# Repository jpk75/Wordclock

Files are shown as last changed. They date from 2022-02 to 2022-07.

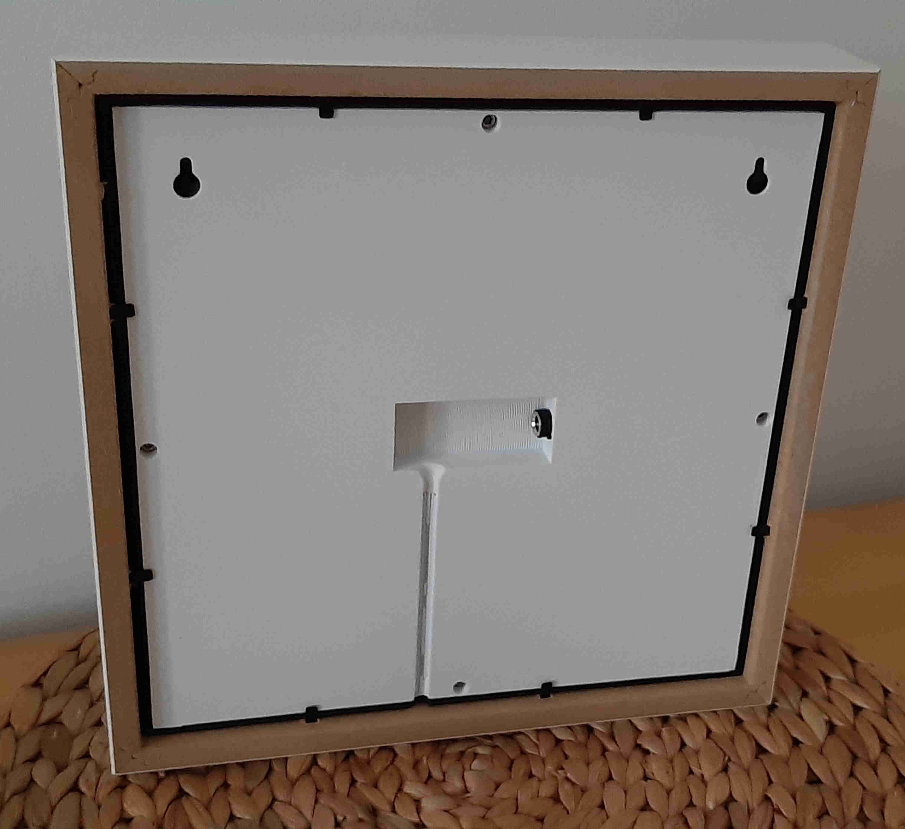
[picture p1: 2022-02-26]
doc/worclock_2.jpg

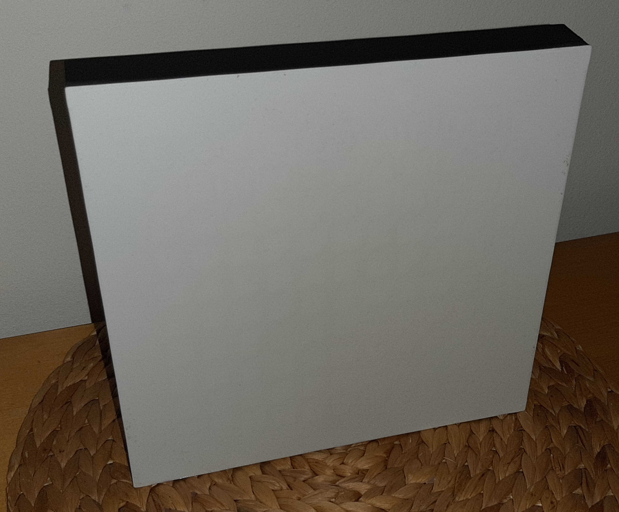
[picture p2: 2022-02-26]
doc/worclock_3.jpg

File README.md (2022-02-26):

# Wordclock

## Model
This project contains a parametric model, wiring description and software to create a wordclock.
Initially it was designed to fit for an IKEA Ribba frame of size 23x23, because I already have some of them at home. But it is possible to adapt to other frame sizes. Also the text and the font can be changed easily. The distance between each letter is chosen so that it is suitable for 60 LED/m WS2812 stripes.

To print all parts, you need to export the frame, the inlay and the back cover as STLs from OpenSCAD.

Each part can be printed without using support. But because of the large size of the frame or back cover, the edges tend to warp. To reduce thiseffect, you can enable support around these edges.

If you want to print the frame with a diffusor, you can set parameter 'generate_diffusor' to true. I recommend to use white PLA for the diffusor and then change to black PLA.

To connect the back cover to the frame, I used M3 inserts in the frame. The holes for these inserts can be adapted to your needs.

## Electronics
The used LED stripes are of type WS2812 with 60 LEDs/m.
The controller board is an ESP-12F module with ESP8266.
As a real time clock a DS3231 module is used.
Optional, a light sensor can be also used. The used module is a BH1750.

## Software
To build the software VisualStudio Code with PlatformIO can be used. Extract the archive 'wordclock_sw.7z' to a folder and open it with VS Code, build it and flash it to the ESP8266. To flash the device, upload the filesystem image 'littlefs.bin' and the application image 'wordclock.bin'.

- Connecting to wifi network
- After boot, the ESP starts an AP. Connect to this AP and enter your wifi credentials.
- After reboot, wordclock will connect to your wifi network and shows its IP address.
- Enter this IP address into the address bar of your internet browser. This will load the config page of the wordclock.

# License
Creative Commons Attribution-NonCommercial-ShareAlike 4.0 International Public License (CC BY-NC-SA 4.0)

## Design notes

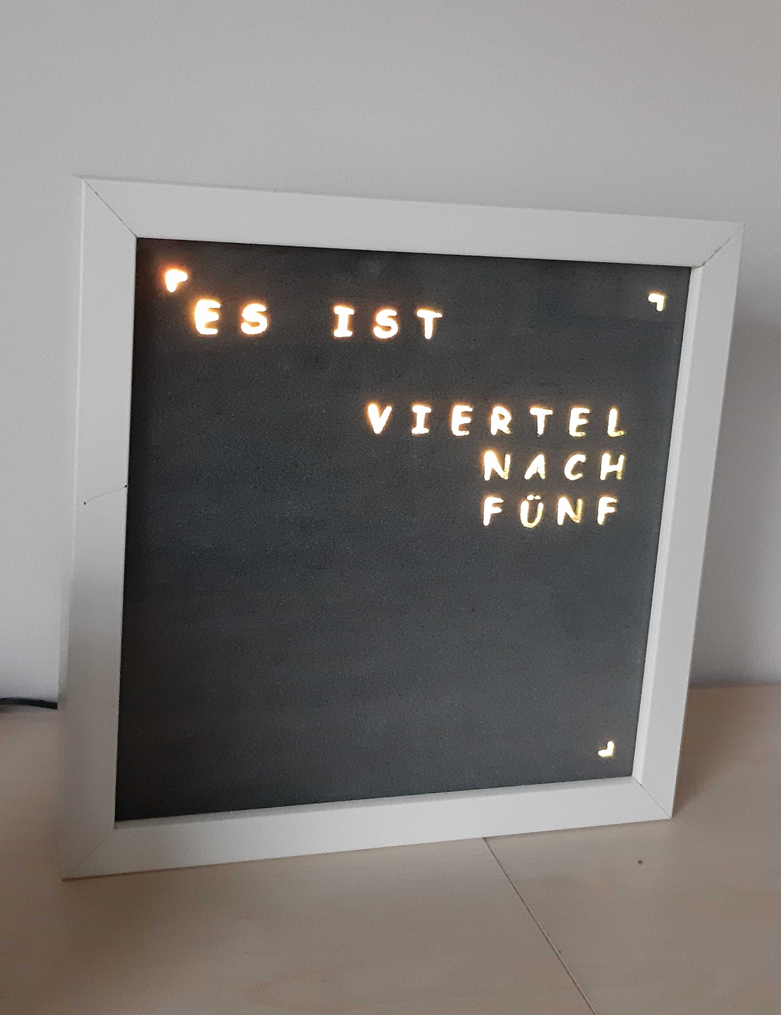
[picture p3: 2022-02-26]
doc/worclock_1.jpg

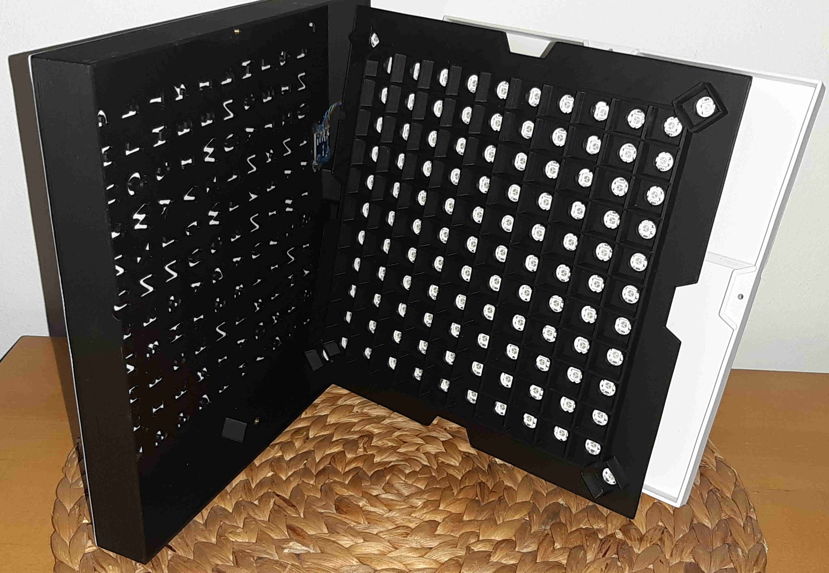
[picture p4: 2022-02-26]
doc/worclock_5.jpg

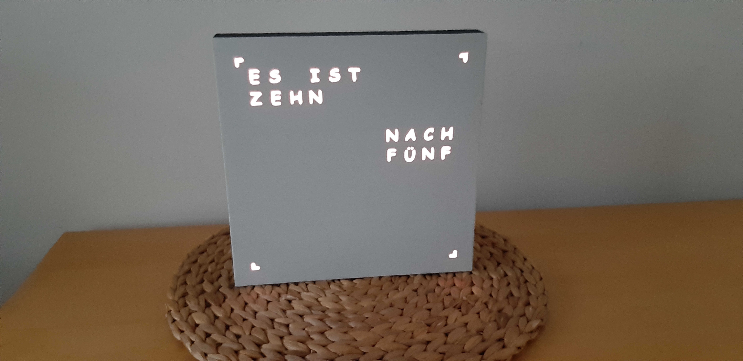
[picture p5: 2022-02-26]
doc/worclock_4.jpg

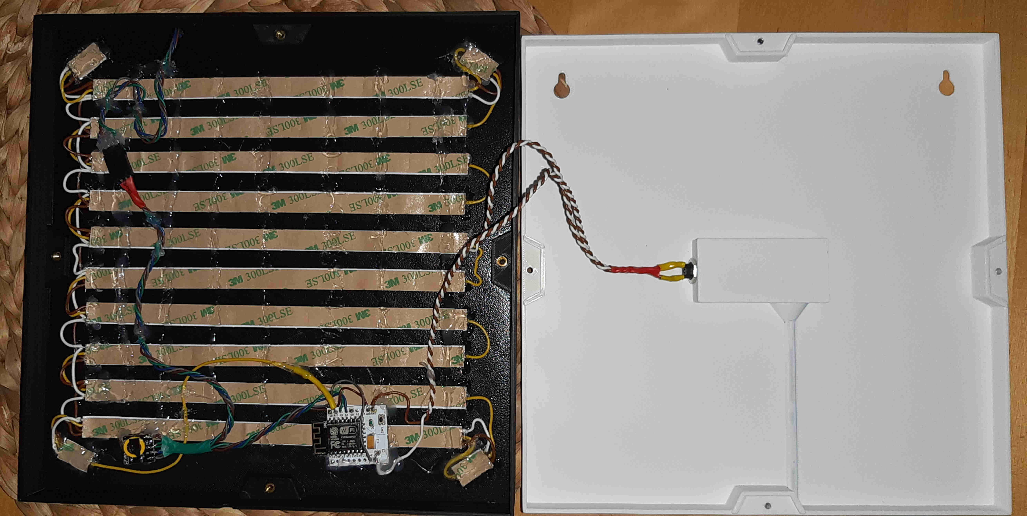
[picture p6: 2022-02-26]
doc/worclock_6.jpg

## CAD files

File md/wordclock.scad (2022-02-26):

/*******************************************************/
/* File: wordclock.scad                                */
/* Description: Parametric Wordclock                   */
/* Date: 2022-02-06                                    */
/* Author: _jpk                                        */
/* License: CCA - Non-Comercial - Share Alike          */
/*******************************************************/
quality_high = false;
quality_factor = 0.3;
generate_frame=true;
generate_inlet=false;
generate_back_cover = false;
generate_cable_guide = true;
generate_brigthness_sensor = true;
generate_diffusor = true;
generate_support = true;

wall_thickness_side = 1.9;  // wall thickness of side walls
wall_thickness_bottom = 1.5; // wall thickness of bottom
diffusor_thickness = 0.6;  // thickness of diffusor
support_thickness = 0.4;    // thickness of support

frame_width = 230;      // total width of word clock frame
frame_depth = 230;       // total depth of word clock frame
frame_height = 28;     // total height of word clock frame
mount_width_1 = 30;     // width 1 of mount
mount_width_2 = 20;     // width 2 of mount
mount_depth = 10;       // depth of mount
mount_height = 15;      // height of mount
mount_hole_d = 5.2;     // hole for screw
mount_offset_x = frame_width/2 - wall_thickness_side;
mount_offset_y = frame_depth/2 - wall_thickness_side;

cableguide_offset_x = -15;  // cable guide offset
cableguide_d = 6;           // diameter of cable guide tube

corner_offset_x=95;      // width of corners
corner_offset_y=95;       // depth of corners
corner_type=2;          // 0=circle, 1=rectangle, 2=tbd
corner_width = 5;       // width of corners (or for type 0: diameter
corner_depth=5;       // depth of corners

stripe_guide_depth=8.25;

base_width = frame_width-(2*wall_thickness_side) - 2;
base_depth = frame_depth-(2*wall_thickness_side) - 2;
base_height_1 = 2;
base_height_2 = 11;
base_height_3 = 2;
base_height_total = base_height_1 + base_height_2 + base_height_3;
base_led_hole_d = 9;
base_mount_tolerance = 0.2;

letter_font="Comic Sans MS:style=Bold";
letter_size=9.5;          // height of letter 
letter_dist=16.6667;       // distance between letters

clock_text="ESKISTAFÜNFZEHNZWANZIGDREIVIERTELVORFUNKNACHHALBAELFÜNFEINSDCWZWEIDREIAUJVIERSECHSNLACHTSIEBENZWÖLFZEHNEUNKUHR";
letter_per_row = 11;        // Number of letter per row

row_cnt = len(clock_text) / letter_per_row;
row_width = letter_per_row * letter_dist;
row_dist = row_width / row_cnt;
row_offset_x = (row_width - letter_dist)/ 2;
row_offset_y = (row_width - row_dist) / 2;

back_cover_width=base_width;
back_cover_depth=base_depth;
back_cover_height=frame_height-base_height_total;

brightness_hole_offset_x = 25;
brightness_hole_offset_y = frame_depth/2-15;
brightness_hole_d = 7;
WordClock();

// Module for creating a word clock frame
module WordClock(){
    echo(len(clock_text));
    echo(row_cnt, row_width, row_dist, row_offset_x, row_offset_y);

;    $fa = 0.5;
    $fs = quality_high ? quality_factor : 1;
    
    if (generate_frame)
        union(){
            color("BlueViolet",1){
                difference(){
                    frame(frame_width, frame_depth, frame_height);
                    corners();
                    
                    clock_text();
                }
            }
            if (generate_diffusor)
                color("White", 0.5){
                    translate([0,0,-(diffusor_thickness+frame_height)/2]) cube([frame_width, frame_depth,diffusor_thickness], center=true);
                }
            if (generate_support){
                
                support_offset_z = (frame_height - support_thickness)/2 + (generate_diffusor ? diffusor_thickness:0);
                translate([-frame_width/2,-frame_depth/2,-support_offset_z]) cylinder(support_thickness, d=20, center=true);
                translate([frame_width/2,-frame_depth/2,-support_offset_z]) cylinder(support_thickness, d=20, center=true);
                translate([frame_width/2,frame_depth/2,-support_offset_z]) cylinder(support_thickness, d=20, center=true);
                translate([-frame_width/2,frame_depth/2,-support_offset_z]) cylinder(support_thickness, d=20, center=true);
            }
        }
    
    
    if (generate_inlet){
        union(){
            base();
           if (generate_support){               
                support_offset_z = base_height_1 + support_thickness/2;
                translate([-base_width/2,-base_depth/2,-support_offset_z]) cylinder(support_thickness, d=20, center=true);
                translate([base_width/2,-base_depth/2,-support_offset_z]) cylinder(support_thickness, d=20, center=true);
                translate([base_width/2,base_depth/2,-support_offset_z]) cylinder(support_thickness, d=20, center=true);
                translate([-base_width/2,base_depth/2,-support_offset_z]) cylinder(support_thickness, d=20, center=true);
            }
        }
    }
    
    if (generate_back_cover){
        color("Green",1) 
            union(){
                back_cover();
                if (generate_support){               
                    support_offset_z = back_cover_height-base_height_1 - support_thickness/2;
                    translate([-base_width/2,-base_depth/2,support_offset_z]) cylinder(support_thickness, d=20, center=true);
                    translate([base_width/2,-base_depth/2,support_offset_z]) cylinder(support_thickness, d=20, center=true);
                    translate([base_width/2,base_depth/2,support_offset_z]) cylinder(support_thickness, d=20, center=true);
                    translate([-base_width/2,base_depth/2,support_offset_z]) cylinder(support_thickness, d=20, center=true);
                }
            }
        }
}

module frame(width=10, depth=10, height=10){
    difference(){
        cube([width, depth, height], center=true);
        translate([0,0,wall_thickness_bottom]){
            cube([width-2*wall_thickness_side, depth-2*wall_thickness_side, height], center=true);
        }
        
        if (generate_brigthness_sensor){
            d = brightness_hole_d;
            h = wall_thickness_bottom+0.2;
            translate([brightness_hole_offset_x, -brightness_hole_offset_y, -(frame_height-h)/2]) cylinder(h=h, r1=(d+wall_thickness_bottom)/2, r2=d/2, center=true);
        }

        if (generate_cable_guide){
            translate([cableguide_offset_x, frame_depth/2, frame_height/2]) 
                rotate([90,0,0]) 
                  cylinder(h=frame_depth/2, d=cableguide_d,center=true);

        }
    }
    mounts([0,-depth/2+wall_thickness_side,-frame_height/2], [0,0,0], h=mount_height);
    mounts([0,-depth/2+wall_thickness_side,-frame_height/2], [0,0,90], h=mount_height);
    mounts([0,-depth/2+wall_thickness_side,-frame_height/2], [0,0,180], h=mount_height);
    mounts([0,-depth/2+wall_thickness_side,-frame_height/2], [0,0,270], h=mount_height);
}

module mounts(offset=[0,0,0], rotation=[0,0,0], h=mount_height, hole=true, outline=0){
    rotate(rotation){
        translate(offset){
            translate([0,0,h/2])
            difference(){
                linear_extrude(height=h, center=true){
                    x1 = mount_width_1/2+outline;
                    x2 = mount_width_2/2+outline;
                    y1 = outline;
                    y2 = mount_depth+outline;
                    polygon([[-x1,y1],[x1,y1],[x2,y2],[-x2,y2]]);
                }
                if (hole) translate([0, mount_depth/2, (h+1)/2]) cylinder(h+1, d=mount_hole_d, center=true);
            }
        }
    }
}
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

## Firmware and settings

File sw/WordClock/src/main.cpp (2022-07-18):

#include "wordclock-config.h"   // include at top
#include <Arduino.h>
#include <ESP8266WiFi.h>
#include <ESP8266WebServer.h>
#include <WiFiManager.h>
#include <DNSServer.h>
#include <EEPROM.h>
#include <time.h>
#include <LittleFS.h>
#include <debug.h>
#include "stringex.h"
#include "debuglog.h"
#include "parameter.h"
#include "timehandler.h"
#include "lighthandler.h"
#include "wordclock.h"
#include "webservice.h"
#include "WebWordclock.h"

const char* VERSION = WORDCLOCK_VERSION;
const char* HOSTNAME_BASE = WORDCLOCK_HOSTNAME;

WiFiManager wifiManager;

Parameter parameter;

String timeZone = NTP_TIMEZONE_DEFAULT;
String ntpServer = NTP_SERVER_DEFAULT;

// NTP available flag
TimeHandler thTime(parameter);

// lightmeter
LightHandler lightMeter(parameter); 

// web service object
WebService webService(parameter);

// NeoPixel control object
WordClock wordclock(parameter, NEOPIXEL_NUMPIXELS, WORDCLOCK_COLS, WORDCLOCK_ROWS, NEOPIXEL_PIN);
WebWordclock webWordclock(parameter, webService);

// extern "C" uint8_t sntp_getreachability(uint8_t);
// bool getNtpServer(bool reply = false) {   
//    ntpAvailable = sntp_getreachability(0) ? true : false;
//    if (!ntpAvailable) configTime(parameter.getTimezone().c_str(), parameter.getNtpServer().c_str());   // set timezone https://github.com/nayarsystems/posix_tz_db/blob/master/zones.csv

//    DebugLog.print("Timezone = "); DebugLog.println(parameter.getTimezone());
//    DebugLog.print("ntpServer = "); DebugLog.println(parameter.getNtpServer());
//    DebugLog.print("NTP Server available = "); DebugLog.println(ntpAvailable);

//    return ntpAvailable;
// }


// setup time
void setupTime(){
   String filename(F("/zones.json"));
   String tz = PARAM_TIMEZONE_CODE_DEFAULT;
   // get timezone from json file
   auto f = LittleFS.open(filename, "r");
   if (f){
      DebugLog.println(F("Open File '") + filename + F("' successful"));
      DebugLog.println(F("parsing file ..."));
      while(f.available()){
         String s = f.readStringUntil('\n');
         String split[2];
         int32_t n = StringEx::StringSplit(s, ':', split, 2);
         if (2 == n) {
            split[0].replace(F("\""), F(""));
            if (split[0] == parameter.getTimezone()){
               split[1].replace(F("\","), F(""));  // 1st remove chars '",'
               split[1].replace(F("\""), F(""));   // 2nd remove char '"'
               tz = split[1];
               DebugLog.println(F("Timezone found: Zone = '") + split[0] + F("', Code = ") + split[1]);
            }
         }
      } 
      DebugLog.println(F("closing file ..."));
      f.close();
   } else {
      DebugLog.println(F("Failed to open File '") + filename + F("'!"));
   }

   DebugLog.println(F("Set Timezone ") + parameter.getTimezone() + F(" (Code = ") + tz + F(")"));
   setTZ(tz.c_str());
   thTime.setNtpServer(parameter.getNtpServer());
   thTime.setUpdateInterval(NTP_UPDATE_INTERVAL);
   thTime.begin();
}

void onParameterChanged(){
   setupTime();
}

void setup() {
//   gdbstub_init();
   Serial.begin(115200);
   Serial.setDebugOutput(true);
   Serial.println();
   Serial.print(F("Wordclock ")); DebugLog.println(VERSION);

   LittleFS.begin();
   Wire.begin();

    //Initialize DebugLog
   DebugLog.init();
   
   // create default host name based on MAC-Address
   String hn = String(HOSTNAME_BASE) + String(F("_")) + WiFi.macAddress();
   hn.replace(":", "");
   parameter.setHostNameDefault(hn);
   parameter.registerChangedCallback(onParameterChanged);

   if (!parameter.read()){
      DebugLog.println(F("Failed to read parameter from EEPROM -> using default values"));
   }

   if (parameter.getHostName().isEmpty()){
      parameter.setHostName(hn);
   }

   String hostName = parameter.getHostName();

   Serial.println(String(F("Hostname = ")) + parameter.getHostName());

   lightMeter.begin();

   wordclock.setup();
   parameter.parameterChanged(false);


   // Set timeout for AP
   WiFi.persistent(true);
   wifiManager.setConfigPortalTimeout(AP_TIMEOUT);

   // start Wifi Manager
   wifiManager.autoConnect(hostName.c_str());

   strncpy(parameter.SSID, WiFi.SSID().c_str(), sizeof(parameter.SSID));
   strncpy(parameter.password, WiFi.psk().c_str(), sizeof(parameter.password));

   DebugLog.println(String(F("Connected to SSID ")) + String(parameter.SSID));
   DebugLog.println(WiFi.localIP());

   // setup time
   setupTime();

   if (parameter.showIP) wordclock.showIp();

   // setup web service
   webService.setup();

   // setup web interface
   webWordclock.setup();

}

void loop() {
   static uint32_t lastNtpUpdate_ms = millis();

   DBG_STATE(1);


   thTime.loop();
   lightMeter.loop();

   DBG_STATE(2);
   
   DebugLog.handle();

   DBG_STATE(3);
   
   wordclock.handle();

   DBG_STATE(4);

   webService.handle();
   DBG_STATE(5);

   if ((millis()-lastNtpUpdate_ms) > NTP_UPDATE_INTERVAL){
      lastNtpUpdate_ms = millis();
   }

   DBG_STATE(6);

   webWordclock.handle();

   DBG_STATE(7);
}

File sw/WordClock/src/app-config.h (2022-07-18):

#pragma once

#define WORDCLOCK_HOSTNAME "wordclock"
#define WORDCLOCK_VERSION "V0.1.0"
#define WORDCLOCK_COLS 11        // number of letters in a row
#define WORDCLOCK_ROWS 10        // number of rows

#define AP_TIMEOUT 240ul  // Timeout in seconds for AP / WLAN config
#define NTP_SERVER_DEFAULT "de.pool.ntp.org" // NTP server
#define NTP_TIMEZONE_DEFAULT  "Europe/Berlin"
#define NTP_TIMEZONE_CODE_DEFAULT  "CET-1CEST,M3.5.0/02,M10.5.0/03"
#define NTP_UPDATE_INTERVAL 3600000ul    // Update time every 1 hour (3600000ms)  

#define NEOPIXEL_PIN 12           // HW pin the LED stripe ist connected to
#define NEOPIXEL_NUMPIXELS  114  // number of LEDs

// RTC
#define USE_RTC 1
#define I2C_ADR_RTC 0x68            // I2C adress of the RTC  DS3231 (Chip on ZS-042 Board)

// Lightsensor
#define USE_LIGHTSENSOR 1
#define I2C_ADR_BH1750 0x23

// Features
#define CALC_SINELUT 0      // disable calulation of sine LUT
//#define CALC_SINELUT 1      // enable calulation of sine LUT

// MQTT
#define USE_MQTT 0
#define MQTT_SERVER "192.168.10.7"
#define MQTT_PORT   1883
#define MQTT_ALIVE_INTERVAL 300000      // MQTT alive message every 5 minutes 
#define MQTT_CLIENT WORDCLOCK_HOSTNAME
#define MQTT_GROUP  "wordclock"
#define MQTT_TOPIC  "${group}/${client}"

// Debugging
#define USE_DBGSTATE 0
#define USE_SERIAL 1
#define USE_TELNET 0

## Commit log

2022-04-09 [bug] all commas were removed from timezone code
    [main.cpp]
2022-04-09 [fix] unnecessary include removed
    [main.cpp]
